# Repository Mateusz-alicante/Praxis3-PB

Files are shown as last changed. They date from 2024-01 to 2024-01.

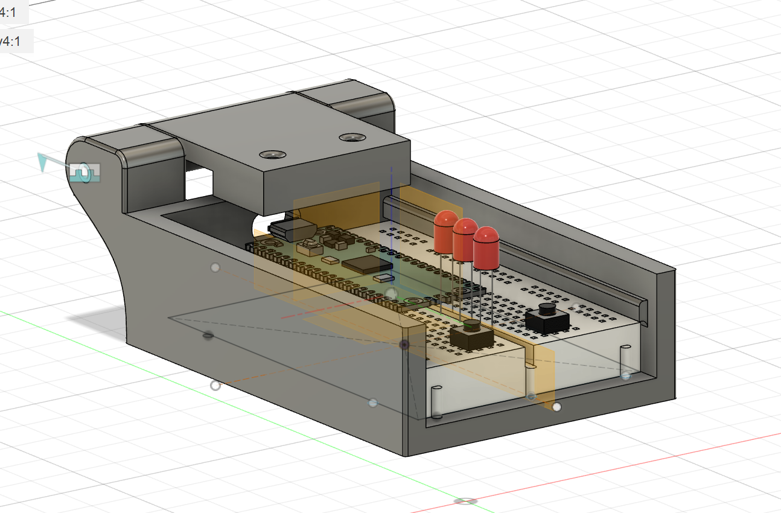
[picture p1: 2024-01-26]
1. Design Process Artifacts/Pictures/Integration/3.Hinge_Lifted_To_Allow_Cable_Room.png

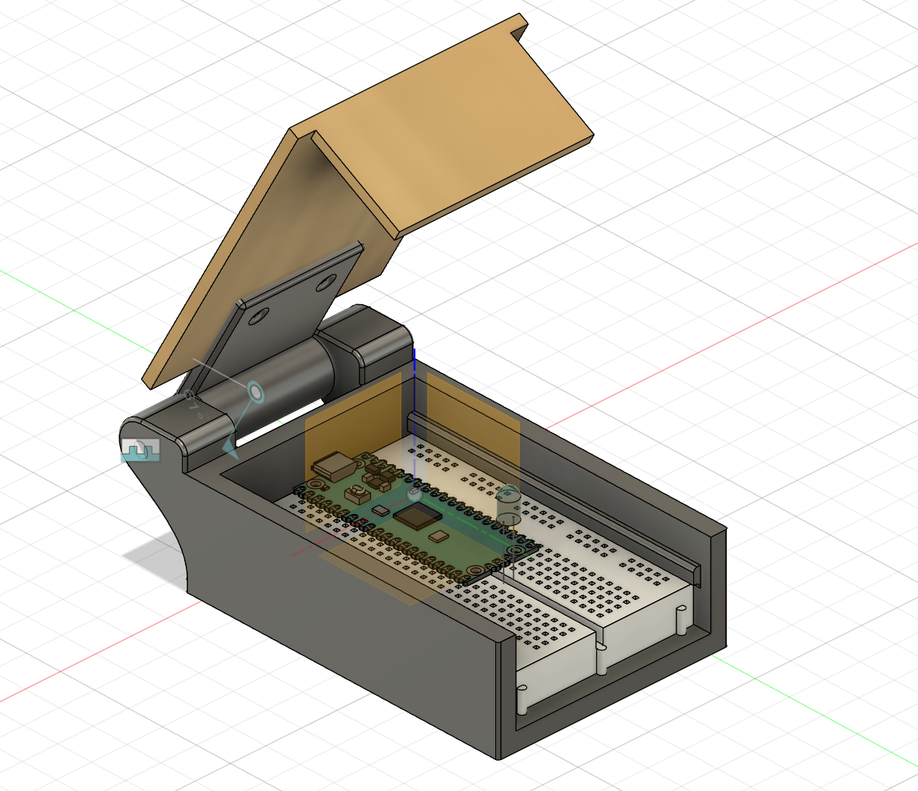
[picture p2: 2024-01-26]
1. Design Process Artifacts/Pictures/Integration/2.Flipped_Breadboard.png

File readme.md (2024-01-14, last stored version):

## Circuit setup:

connect the components as specified by the constants of the main.py file:

WORKER_LEDS -> GP17

PLANT_LEDS -> GP16

WORKER_BUTTON -> GP15

PLANT_BUTTON -> GP14

## Editing files:

### .ffz files:

Edit using Fritzing. The software is paid but you can find free versions online (it used to be free)

### .drawio files:

Go to [draw.io](https://app.diagrams.net/) and open the file. You can edit it online and export it as a .png or .svg

## Todo:

- [x] Change the code to support a RGB LED for the worker lights instead of a standard LED (Harry and Mateusz)
- [ ] Develop procedure to measure the light intensity as for the handout
- [ ] Develop procedure to measure the soil moisture as for the handout
- [ ] calculate resistor values
- [ ] cover CAD

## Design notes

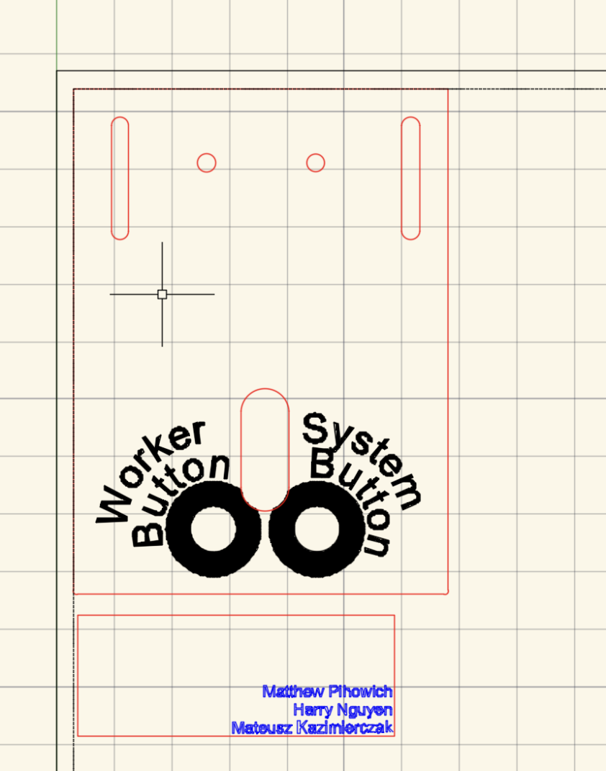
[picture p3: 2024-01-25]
1. Design Process Artifacts/Pictures/Prototyping/Initial_Laser_Cut_Idea.webp

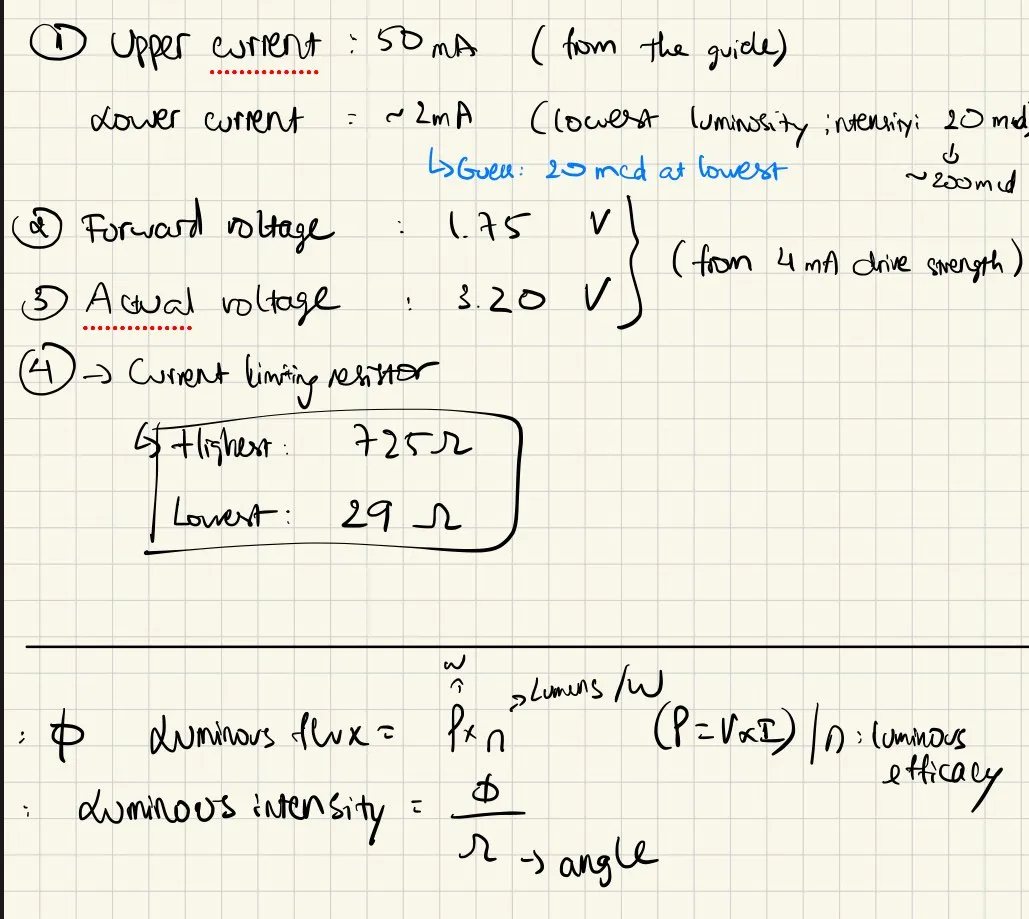
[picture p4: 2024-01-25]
1. Design Process Artifacts/Pictures/Prototyping/Initial_Resistor_And_DLI_Hand_Calculation.webp

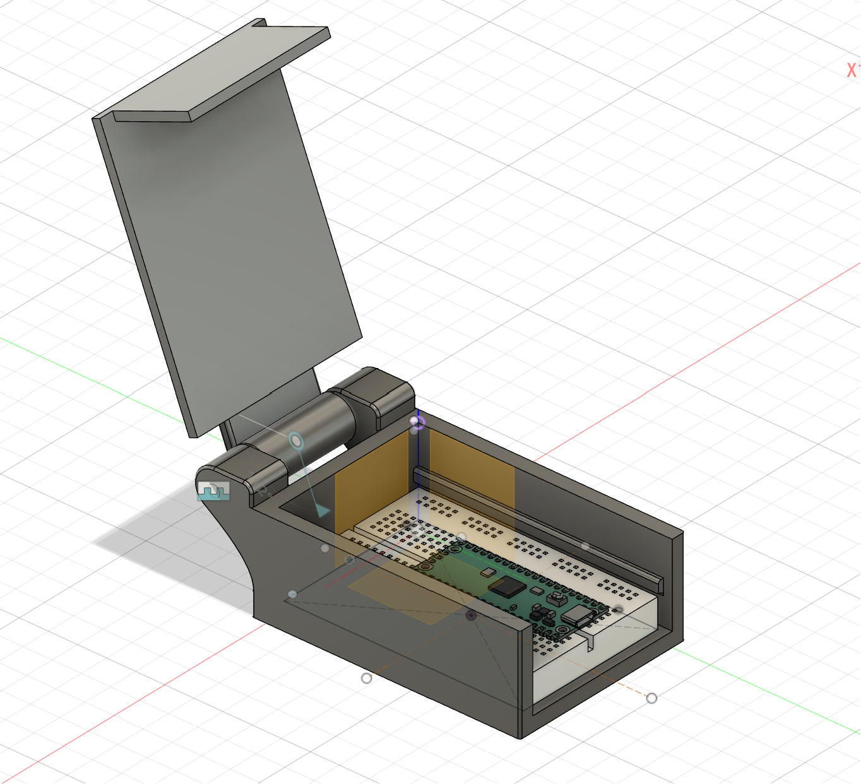
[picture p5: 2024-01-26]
1. Design Process Artifacts/Pictures/Integration/1.Recognize_Hinge_Clashes_With_Planned_Button_Locations.png

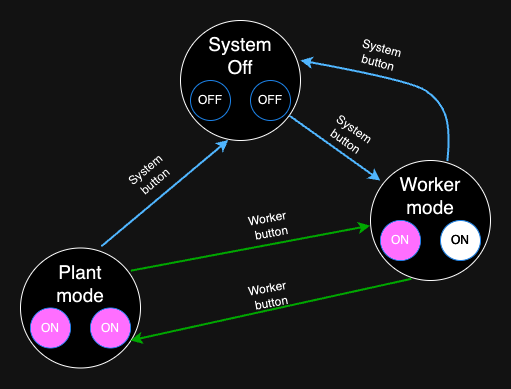
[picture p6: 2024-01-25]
1. Design Process Artifacts/Pictures/Prototyping/Initial_State_Diagram.webp

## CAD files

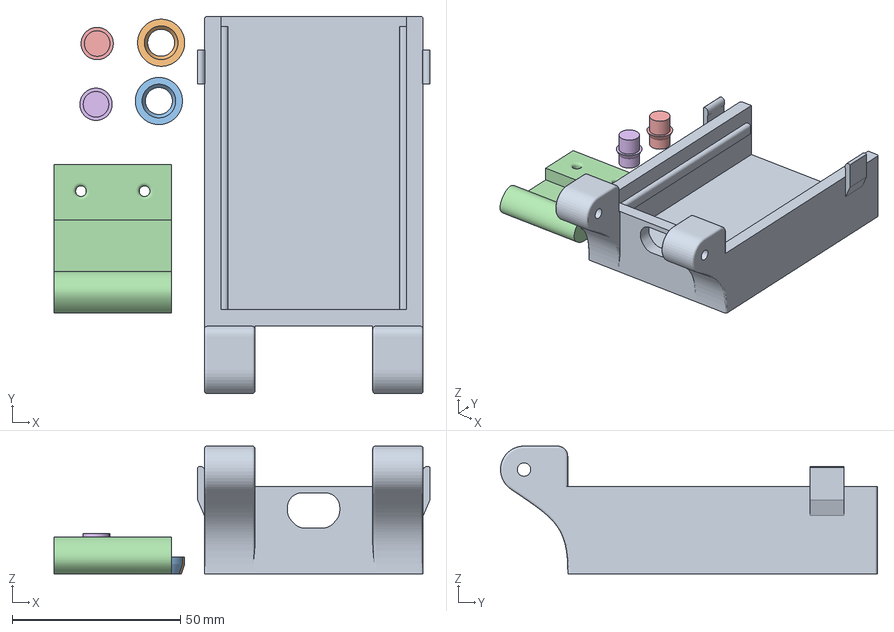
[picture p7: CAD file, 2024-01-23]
2. Final Design Artifacts/Final_CAD_CAM/Final_3D_Print.3mf
111.7 x 112.0 x 38.0 mm
Box 3d model v34.stl
Button Housing v3.stl x 2
Hinge_w_holes v6.stl
Button v2.stl x 2

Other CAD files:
2. Final Design Artifacts/Final_CAD_CAM/Final_Lasercut.dwg
2. Final Design Artifacts/Final_CAD_CAM/Final_CAD_Assembly.f3z

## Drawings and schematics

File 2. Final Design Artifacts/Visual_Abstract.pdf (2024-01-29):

# GREENHOUSE GOBLIN

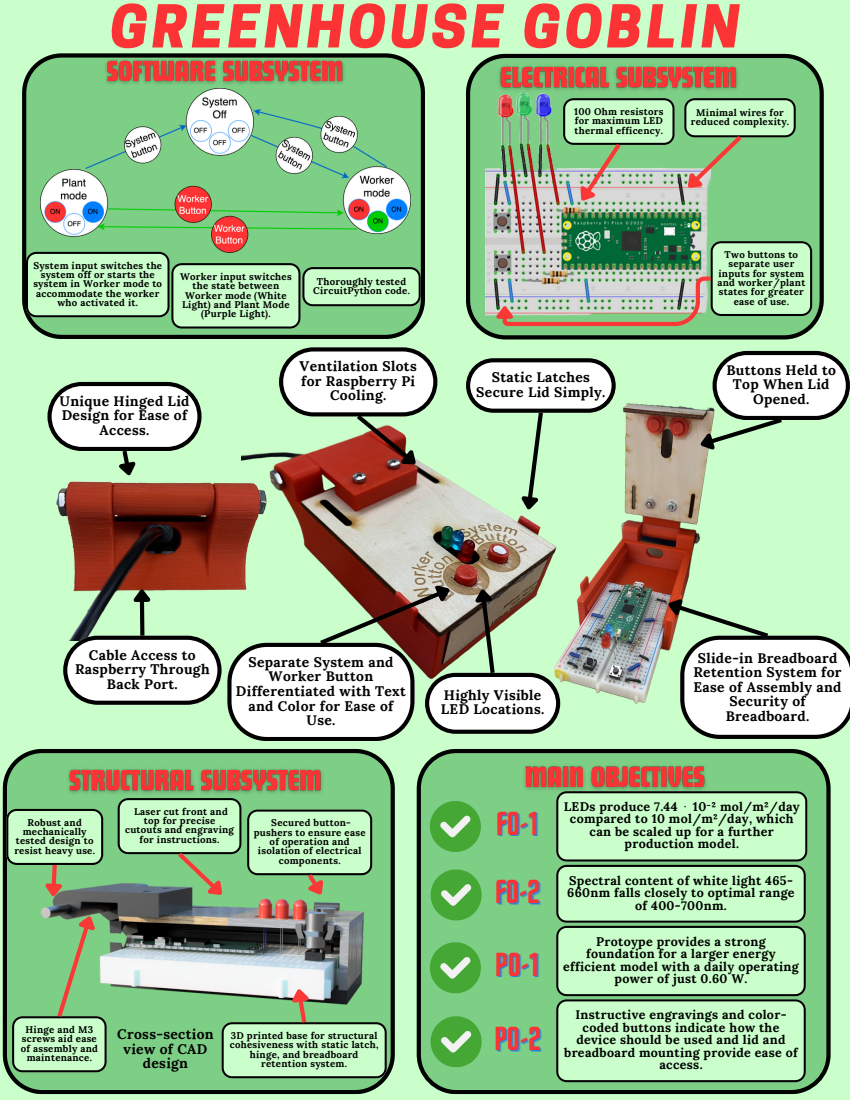
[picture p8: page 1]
Use.; Highly Visible LED Locations.; Thoroughly tested CircuitPython code.; access.

100 Ohm resistors
for maximum LED
thermal efficency.

Minimal wires for
reduced complexity.

Two buttons to
separate user
inputs for system
and worker/plant
states for greater
ease of use.

System input switches the
system off or starts the
system in Worker mode to
accommodate the worker
who activated it.

Worker input switches
the state between Worker mode (White
Light) and Plant Mode
(Purple Light).

Ventilation Slots
for Raspberry Pi
Cooling.

Buttons Held to
Top When Lid
Opened.

Static Latches
Secure Lid Simply.

Unique Hinged Lid
Design for Ease of
Access.

Cable Access to
Raspberry Through
Back Port.

Slide-in Breadboard
Retention System for
Ease of Assembly and
Security of
Breadboard.

Separate System and
Worker Button
Differentiated with Text
and Color for Ease of

Laser cut front and
top for precise
cutouts and engraving
for instructions.

LEDs produce 7.44 ⋅ 10⁻² mol/m²/day
compared to 10 mol/m²/day, which

Robust and
mechanically
tested design to
resist heavy use.

Secured button-
pushers to ensure ease
of operation and
isolation of electrical
components.

can be scaled up for a further
production model.

Spectral content of white light 465-

660nm falls closely to optimal range

Protoype provides a strong
foundation for a larger energy

efficient model with a daily operating

power of just 0.60 W.

Instructive engravings and color-
coded buttons indicate how the

Hinge and M3
screws aid ease
of assembly and
maintenance.

Cross-section
view of CAD
design

3D printed base for structural
cohesiveness with static latch,
hinge, and breadboard
retention system.

device should be used and lid and
breadboard mounting provide ease of

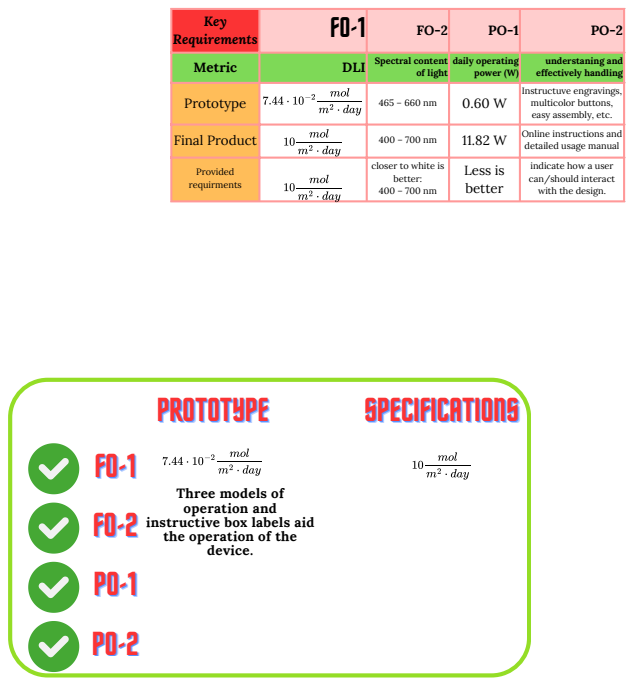
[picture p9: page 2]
PROTOTYPE; SPECIFICATIONS

Key Requirements | FO-1 | FO-2 | PO-1 | PO-2

Metric | DLI | Spectral content of light | daily operating power (W) | understaning and effectively handling
Prototype | | 465 – 660 nm | 0.60 W | Instructuve engravings, multicolor buttons, easy assembly, etc.

Final Product | | 400 – 700 nm | 11.82 W | Online instructions and detailed usage manual

Provided requirments | | closer to white is better: 400 – 700 nm | Less is better | indicate how a user can/should interact with the design.

instructive box labels aid
the operation of the
device.

Three models of
operation and

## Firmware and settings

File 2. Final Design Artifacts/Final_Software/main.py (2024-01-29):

'''
Course: ESC 204
Team: 0105-08
Project: Plant Monitoring System
Description: This file contains the main program that will run on the Raspberry Pi Pico.
'''

import time
import board
import digitalio

LED_PINS = {
    'RED': board.GP17,  # FINAL PIN
    'BLUE': board.GP12,  # FINAL PIN
    'GREEN': board.GP19  # FINAL PIN
}

WORKER_BUTTON = board.GP10  # FINAL PIN
SYSTEM_BUTTON = board.GP22  # FINAL PIN


class LED_CONTROLLER:
    def __init__(self, redPin, greenPin, bluePin):

        # initialize the LEDs
        self.redPin = digitalio.DigitalInOut(redPin)
        self.greenPin = digitalio.DigitalInOut(greenPin)
        self.bluePin = digitalio.DigitalInOut(bluePin)

        self.redPin.direction = digitalio.Direction.OUTPUT
        self.greenPin.direction = digitalio.Direction.OUTPUT
        self.bluePin.direction = digitalio.Direction.OUTPUT

        # When the LEDs are initialized (worker mode will be enabled by default)
        self.LEDs_white()

    # Turn off all three LEDs
    def LEDs_off(self):
        self.redPin.value = False
        self.greenPin.value = False
        self.bluePin.value = False

    # LEDs for the plants
    def LEDs_pink(self):
        self.redPin.value = True
        self.greenPin.value = False
        self.bluePin.value = True

    # LEDs for worker
    def LEDs_white(self):
        self.redPin.value = True
        self.greenPin.value = True
        self.bluePin.value = True


class BOARD_CONTROLLER:
    def __init__(self):

        # Initialize the board's LED
        self.Leds = LED_CONTROLLER(
            LED_PINS['RED'], LED_PINS['GREEN'], LED_PINS['BLUE'])

        self.board_led = digitalio.DigitalInOut(board.LED)
        self.board_led.direction = digitalio.Direction.OUTPUT

        # Initialize the buttons
        self.WorkerButton = digitalio.DigitalInOut(WORKER_BUTTON)
        self.WorkerButton.direction = digitalio.Direction.INPUT
        self.WorkerButton.pull = digitalio.Pull.UP  # Set internal pull-up resistor

        self.SystemButton = digitalio.DigitalInOut(SYSTEM_BUTTON)
        self.SystemButton.direction = digitalio.Direction.INPUT
        self.SystemButton.pull = digitalio.Pull.UP

        self.state = {
            'Worker': 1,  # Indicates if the worker mode is enabled
            'System': 1,   # Indicates if the system KEDs are on
            'Previous_WORKER_BUTTON': 0,
            'Previous_SYSTEM_BUTTON': 0,
        }

        # Turn on the board LED to indicate that the program has started
        self.board_led.value = True

    def updateState(self):
        # Check if the buttons have been pressed since the last loop
        if self.state['Previous_WORKER_BUTTON'] != self.WorkerButton.value and self.WorkerButton.value == 0:
            # This will check for negative edges of the worker button
            self.state['Worker'] = not self.state['Worker']

        if self.state['Previous_SYSTEM_BUTTON'] != self.SystemButton.value and self.SystemButton.value == 0:
            # This will check for negative edges of the plant button
            self.state['System'] = not self.state['System']

            # When the system is turned on, the worker mode is turned on.
            # When the system is turned off, the worker mode is also turned off.
            self.state['Worker'] = self.state['System']

    def updateLEDs(self):
        # Update the LED based on the state
        if self.state['System'] == 0:
            # If the system is off, turn off all of the LEDs
            self.Leds.LEDs_off()

        # The following cases will only be applied if the system is on
        elif (self.state['Worker'] == 0):
            # If the worker mode is disabled, turn on the plant LEDs,
            self.Leds.LEDs_pink()
        else:
            # If the worker mode is enabled, turn on the worker LEDs,
            self.Leds.LEDs_white()

    def loop(self):
        while True:
            # Update the state and LEDs
            self.updateState()
            self.updateLEDs()

            # Update the previous button values
            self.state['Previous_WORKER_BUTTON'] = self.WorkerButton.value
            self.state['Previous_SYSTEM_BUTTON'] = self.SystemButton.value

            time.sleep(0.5)


# Initialize the controller instance
controller = BOARD_CONTROLLER()

# Run the loop
controller.loop()

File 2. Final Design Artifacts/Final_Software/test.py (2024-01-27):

'''
Course: ESC 204
Team: 0105-08
Project: Plant Monitoring System
Description: 
This file replaces imported libraries that rely on being executed on the board by 
custom objects that simulate the state of the board. Then the code written for the board 
is tested using these objects, which allows us to inspect the state of the object (which simulated
the board) at each moment.

The different test cases are designed to test edge cases for the functionality.
Test cases should start at very basic to more advanced functionality to aid debugging.
'''


class LED_CONTROLLER:
    def __init__(self):
        self.redPin = {"value": False}
        self.greenPin = {"value": False}
        self.bluePin = {"value": False}

        self.LEDs_white()

    def LEDs_off(self):
        self.redPin["value"] = False
        self.greenPin["value"] = False
        self.bluePin["value"] = False

    def LEDs_pink(self):
        self.redPin["value"] = True
        self.greenPin["value"] = False
        self.bluePin["value"] = True

    def LEDs_white(self):
        self.redPin["value"] = True
        self.greenPin["value"] = True
        self.bluePin["value"] = True


class BOARD_CONTROLLER:
    def __init__(self):
        # Initialize the LEDs
        self.Leds = LED_CONTROLLER()

        # Initialize the buttons
        self.WorkerButton = {"value": True}

        self.SystemButton = {"value": True}

        self.state = {
            'Worker': 1,  # Indicates if the worker mode is enabled
            'System': 1,   # Indicates if the system KEDs are on
            'Previous_WORKER_BUTTON': 0,
            'Previous_SYSTEM_BUTTON': 0,
        }

    def updateState(self):
        # Check if the buttons have been pressed since the last loop
        if self.state['Previous_WORKER_BUTTON'] != self.WorkerButton["value"] and self.WorkerButton["value"] == 0:
            # This will check for negative edges of the worker button (when the button is pressed)
            self.state['Worker'] = not self.state['Worker']

        if self.state['Previous_SYSTEM_BUTTON'] != self.SystemButton["value"] and self.SystemButton["value"] == 0:
            # This will check for negative edges of the plant button (when the button is pressed)
            self.state['System'] = not self.state['System']

            # When the system is turned on, for the convenience of the user, the worker mode is also turned on.
            # When the system is turned off, the worker mode is also turned off.
            # (if someone is there to turn the system on, he will appreciate the worker mode being on)
            self.state['Worker'] = self.state['System']

    def updateLEDs(self):
        # Update the LED based on the state
        if self.state['System'] == 0:
            # If the system is off, turn off all of the LEDs
            self.Leds.LEDs_off()

        # The following cases will only be applied if the system is on
        elif (self.state['Worker'] == 0):
            # If the worker mode is disabled, turn on the plant LEDs, and turn the worker LEDs to a specific colour (e.g red)
            self.Leds.LEDs_pink()
        else:
            # If the worker mode is enabled, turn on the worker LEDs, and turn on the plant LEDs
            self.Leds.LEDs_white()

    def singleLoop(self):
        # Update the state and LEDs
        self.updateState()
        self.updateLEDs()

        # Update the previous button values
        self.state['Previous_WORKER_BUTTON'] = self.WorkerButton["value"]
        self.state['Previous_SYSTEM_BUTTON'] = self.SystemButton["value"]


controller = BOARD_CONTROLLER()

# Test 1: Check that when the system is just enabled, make sure the worker mode is on
# color should be white
assert controller.state['Worker'] == 1
assert controller.state['System'] == 1
assert controller.Leds.redPin['value'] == True
assert controller.Leds.greenPin['value'] == True
assert controller.Leds.bluePin['value'] == True
print("Test 1 passed")

# Test 2: After one loop, check that the worker mode is still on
controller.__init__()
controller.singleLoop()
assert controller.state['Worker'] == 1
assert controller.state['System'] == 1
assert controller.Leds.redPin['value'] == True
assert controller.Leds.greenPin['value'] == True
assert controller.Leds.bluePin['value'] == True
print("Test 2 passed")

# Test 3: After pressing the worker button, check that the worker mode is off
controller.__init__()
controller.SystemButton['value'] = True
controller.singleLoop()
controller.WorkerButton['value'] = False
controller.singleLoop()
assert controller.state['Worker'] == 0
assert controller.state['System'] == 1
assert controller.Leds.redPin['value'] == True
assert controller.Leds.greenPin['value'] == False
assert controller.Leds.bluePin['value'] == True
print("Test 3 passed")

# Test 4: After pressing the worker button, check that the worker mode is off, check after several cycles
controller.__init__()
controller.SystemButton['value'] = True
controller.singleLoop()
controller.WorkerButton['value'] = False
controller.singleLoop()
controller.singleLoop()
controller.singleLoop()
assert controller.state['Worker'] == 0
assert controller.state['System'] == 1
assert controller.Leds.redPin['value'] == True
assert controller.Leds.greenPin['value'] == False
assert controller.Leds.bluePin['value'] == True
print("Test 4 passed")

# Test 5: After pressing the system button, check that the worker mode is on
controller.__init__()
controller.SystemButton['value'] = True
controller.singleLoop()
controller.WorkerButton['value'] = False
controller.singleLoop()
controller.singleLoop()
controller.WorkerButton['value'] = True
controller.singleLoop()
controller.singleLoop()
assert controller.state['Worker'] == 0
assert controller.state['System'] == 1
assert controller.Leds.redPin['value'] == True
assert controller.Leds.greenPin['value'] == False
assert controller.Leds.bluePin['value'] == True
print("Test 5 passed")

# Test 6: When the system off button is pressed, check that the system turns off
controller.__init__()
controller.SystemButton['value'] = True
controller.singleLoop()
controller.SystemButton['value'] = False
controller.singleLoop()
controller.SystemButton['value'] = True
controller.singleLoop()
assert controller.state['Worker'] == 0
assert controller.state['System'] == 0
assert controller.Leds.redPin['value'] == False
assert controller.Leds.greenPin['value'] == False
assert controller.Leds.bluePin['value'] == False
print("Test 6 passed")
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

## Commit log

2024-01-14 init commit
    [Sketch.fzz]
2024-01-14 Modify singular LED to RGB LED
2024-01-14 added autocad files for case
    [laser case additional file.dwg, laser case.dwg]
2024-01-17 updated state diagram
    [Sketch.fzz, laser case additional file.dwg]
2024-01-19 improved folder structure
    [Box 3d model v34.stl, Button Housing v3.stl, Button v2.stl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]
2024-01-19 fixed code and added test cases
    [main.py, test.py]
2024-01-19 small fix (turn worker mode off when system is turned off)
    [main.py, test.py]
2024-01-19 adjusted pin numbers for final design
    [laser_cut.dwg]
2024-01-23 Add Print Statements for Debugging
    - System Active
    - Worker Mode
    - LED State
    - Worker button
    - System button
    - Delay system by 0.5s for accuracy
2024-01-23 added laser cut myfab submission
2024-01-23 Organizing Folder
    Organization!
    [Box 3d model v34.stl, Button Housing v3.stl, Button v2.stl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]
2024-01-23 More Organization
    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
    [Final_3D_Print.3mf, Final_CAD_Assembly.f3z, Final_Lasercut.dwg]
2024-01-23 More Updates and Evidence
    Updates
    [Final_3D_Print.3mf, Final_CAD_Assembly.f3z, Final_Lasercut.dwg]
2024-01-24 More Sorting
    Sort sort sort
    [Final_3D_Print.3mf, Final_CAD_Assembly.f3z, Final_Lasercut.dwg]
2024-01-24 Fix indent
    Fix indent
    [main.py]
2024-01-24 moved diagrams into correct folder
    [Circuit_Sketch_Fritzing.fzz]
2024-01-25 Added artifacts from discord (mainly pictures)
    [Circuit_Sketch_Fritzing.fzz]
2024-01-25 Remove Print statements and add comments
2024-01-26 minor changes to software comments and CAD artifact placement
2024-01-26 Create Hinge_Pin_Installed.jpg
    Final_Commit_For_The_Night
2024-01-27 updated circuit diagram
    [Circuit_Sketch_Fritzing.fzz]
2024-01-27 Everything Changes
    [Circuit_Sketch_Fritzing.fzz, Final_3D_Print.3mf, Final_CAD_Assembly.f3z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]
2024-01-27 removed uneccesary print statement from test file
2024-01-27 added key design decisions for circuit
2024-01-29 added design decision images and fixed source file styling
    [main.py]
